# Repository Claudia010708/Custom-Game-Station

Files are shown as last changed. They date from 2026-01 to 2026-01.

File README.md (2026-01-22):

# Custom-Game-Station
Project results of "ASSIST HEIDI - Designing and implementing Assistive Tools for people with disabilities" course.

A Custom Game Station designed for specifical needs of our co-designer. It is a multifunctional adaptive system projected to replace standard joystick and triggers. Specifically, the user requested a customized system to play "Blue Prince", a game requiring strategic navigation and interaction, but can be adapted to easily play multiple games.

## Product overview
This solution is composed of 1 Puck.js microcontroller, which could be easily connected wirelessly to a PC through web Bluetooth. Connected to this, 2 switch buttons and a custom 3D printed support. The solution is meant to be applied on a wheelchair.

    

## Key Features
Wheelchair Joystick:
* Could work both as PC mouse or WASD keys on keyboard, it depends on the selected modality
* Could be recalibrated every time needed
* Adjustable Sensitivity: Settings to adjust joystick sensitivity to individual needs.

Top Cover:
* Holds the batteries for the Puck.js
* Hosts a switch button
* Hosts a plug-in connector to an additional button, the Side-Knee-Button

Side-Knee-Button:
* Is mounted on a Side-Knee-Holder, meant to be attached on the inner side of the wheelchair
* Easy to use, convenient positioning and easy operation with minimal effort

## Technical specifications
* Microcontroller: Puck.js with Bluetooth Low Energy (BLE) support
* Power Supply: Battery-powered with two AAA Alkaline (1.5 V) batteries
* Compatibility: Compatible with Windows, macOS, and Linux operating systems
* Range: Up to 10 meters wireless range.

## Material
* 1x Puck.js microcontrollers
* Glue
* 5x Pair of small connectors
* 2x Switch buttons
* 1x Jack Connector
* 3D printed devices (Joystick Top, Joystick cap, Top Cover, Side Knee holder, Side Knee Button holder)
* Elastic band 10 mm thick

## User Documentation
* [Additional information - About our Project](Additional_Information.pdf)
* [User Manual](User%20Manual/)
* [CAD files](CAD%20Files/)

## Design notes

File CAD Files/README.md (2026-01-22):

# 3D Printing Instructions

This section provides the optimal printing parameters used for the components of the **ASSIST HEIDI** project (STL files included in this repository).

## 🖨️ Print Settings (Slicer Configuration)

Based on the verified configurations from **PrusaSlicer** shown in the documentation:

| Parameter | Setting |
| :--- | :--- |
| **Printer** | Original Prusa i3 MK3S & MK3S+ |
| **Nozzle Diameter** | 0.6 mm |
| **Layer Height** | 0.30 mm (Quality) |
| **Filament** | Prusa PLA |
| **Infill** | 15% |
| **Supports** | Organic, Everywhere |
| **Brim** | Enabled (for extra bed adhesion) |

## 💰 Printing Estimates (Cost & Time)

Below are the estimated costs and printing times calculated using **PrusaSlicer** (Normal Mode):

| Component / Plate | Included Files | Estimated Cost | Printing Time |
| :--- | :--- | :---: | :---: |
| **Cover** | cover_fin14.01.3mf | € 1.64 | 2h 33m |
| **Accessories Kit** (Printed together) | side holder.stl, Side knee button 3.0.stl, Joystick cap.stl, my Joystick body.stl | € 1.74 | 3h 34m |

> **Tip:** The accessories are optimized to be printed simultaneously on the same build plate.

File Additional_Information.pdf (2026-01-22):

# Custom-Game-

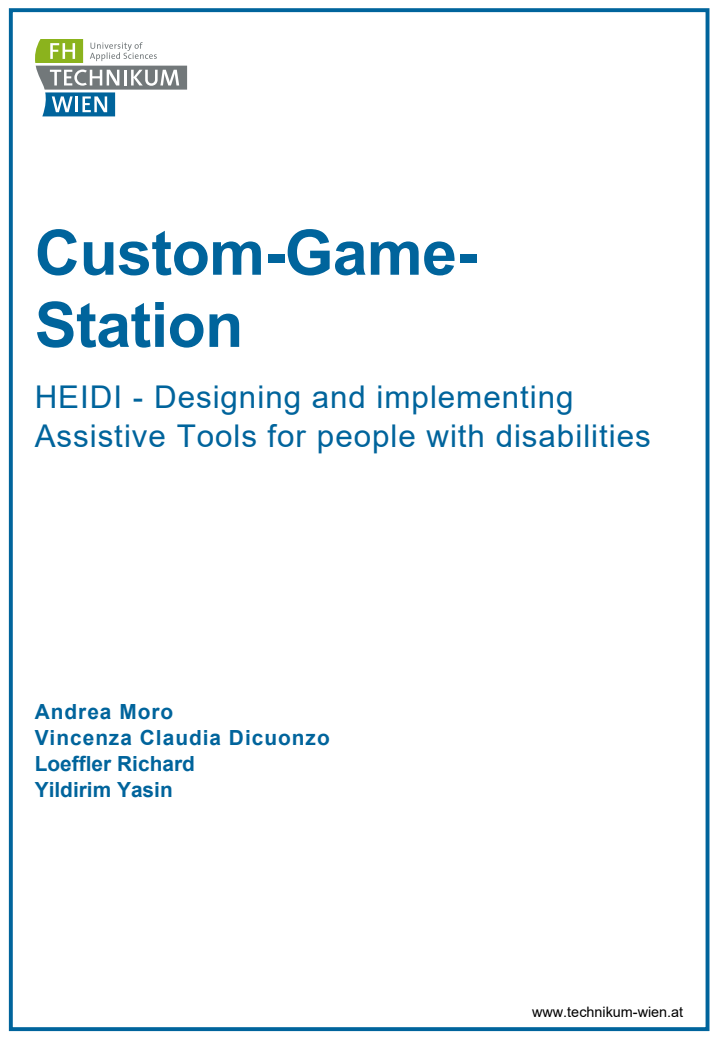
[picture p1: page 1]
Station

HEIDI - Designing and implementing
Assistive Tools for people with disabilities

Andrea Moro
Vincenza Claudia Dicuonzo
Loeffler Richard (https://moodle.technikum-wien.at/user/view.php?id=36255&course=31281)
Yildirim Yasin (https://moodle.technikum-wien.at/user/view.php?id=36939&course=31281)

www.technikum-wien.at

# PROJECT OVERVIEW

Project results of "ASSIST HEIDI - Designing and implementing Assistive Tools for people with disabilities" course.

### Our Team

The Trentino Team “For this project, we embraced the challenge to better understand the possibilities that assistive technologies offer. Our journey focused on bridging the gap between technical constraints and human-centered design.”

### Problem Statement and User Request

The primary challenge regards the fact that conventional gaming controllers require fine motor precision, which results inaccessible to the user. The goal was to design and develop a multifunctional adaptive system to replace standard joysticks and triggers. Specifically, the user requested a customized interface to play "Blue Prince", a game requiring strategic navigation and interaction that, in its original form, exceeded the physical reach and coordination capabilities of our co-designer.

The user is affected by Cerebral Palsy, characterized by poor coordination, muscle stiffness (spasticity), weakness, and tremors. These factors make traditional button-mapping or holding a controller impossible.

Despite these limitations, the following residual functions were identified as inputs for the adaptive system:

- Upper Body: Control of the left arm (though movements are stiff).
- Motor Skills: Sufficient dexterity in the left hand to operate a communication device keyboard and a wheelchair joystick.
- Lower Body: Capability to extend both legs from a sitting position and perform seated knee raises and lateral movements.
- Ocular Control: High proficiency in using eye-tracking systems.

### Solution developed

The implemented solution is a custom Assistive Game Station designed to translate physical actions into digital gameplay. It consists of:

- Smart Joystick: Equipped with a Puck.js microcontroller that senses physical tilts and translates them into in-game perspective and movements.
- Dual-Button Interface: Includes two mechanical switches to replace basic game functions, specifically designed for games that do not require high-speed or fine motor control.

Our project builds upon the foundations of the "Wheely-Joystick-Mouse", an open-source initiative, available here: https://github.com/inclusion-international/Wheely-Joystick-Mouse.git

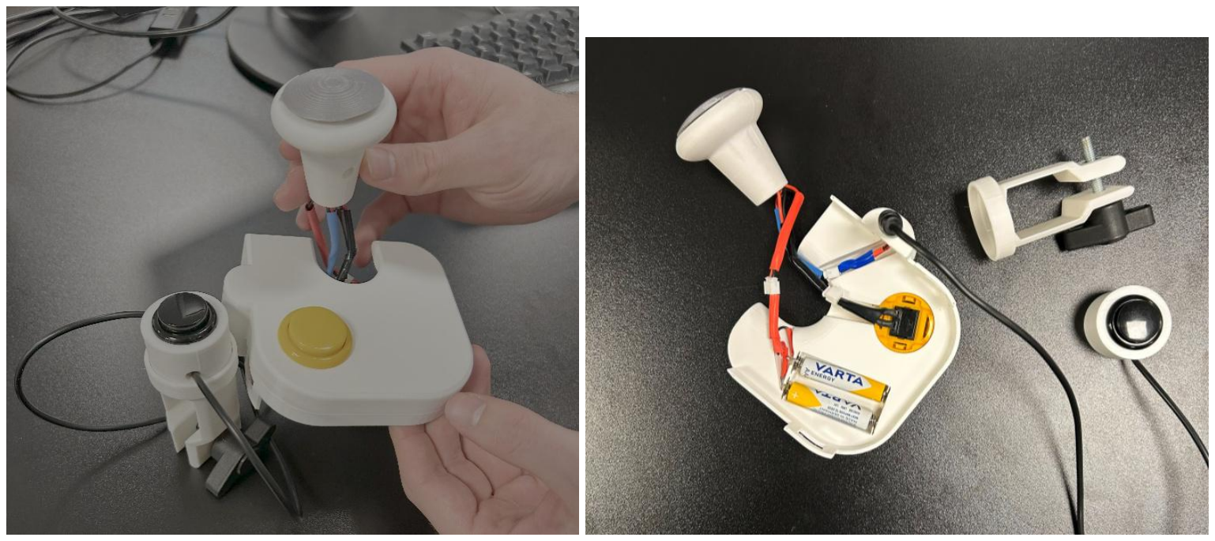
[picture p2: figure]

### Accessories and Instructions

### Cost Estimation

The final product, including the Puck.js microcontroller, mechanical buttons, 3D printed components, and connectors, is estimated to cost between €42 and €43. This makes the device a cost-effective assistive solution compared to commercial alternatives.

### System Usage

Following the instructions provided in the “User manual“, alongside a detailed “Electrical scheme“ it is possible to mount and run the final system.

Once mounted, the system operates wirelessly via Bluetooth. The user can interact with the game by tilting the joystick (sensing movements through the Puck.js) and using the two mechanical buttons for primary game functions. The side knee button is specifically positioned to allow for accessible triggering without requiring fine hand motor control. The details about the translation of the commands are also available in the ”User manual”.

### Acknowledgments

This project was developed within the framework of the ASSIST HEIDI initiative, drawing inspiration from and building upon established open-source assistive controller concepts. We would like to express our gratitude to our co-designer for their participation throughout the co-creation process; their continuous feedback and testing were fundamental in shaping the final prototype to meet realworld accessibility needs

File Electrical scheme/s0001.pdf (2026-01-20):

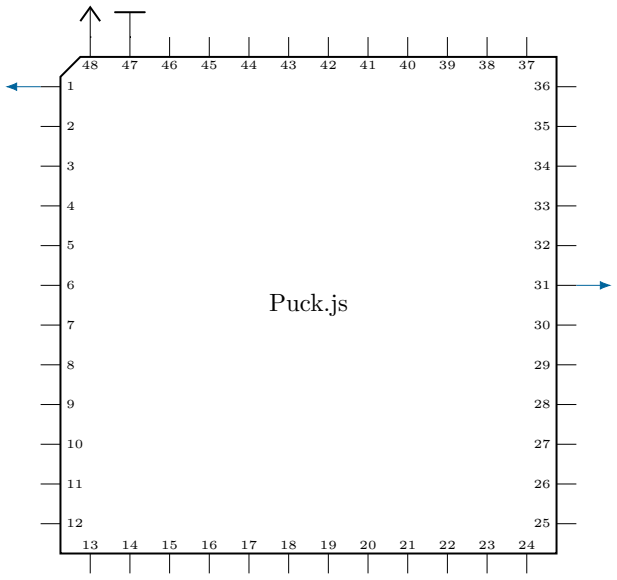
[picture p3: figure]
Puck.js
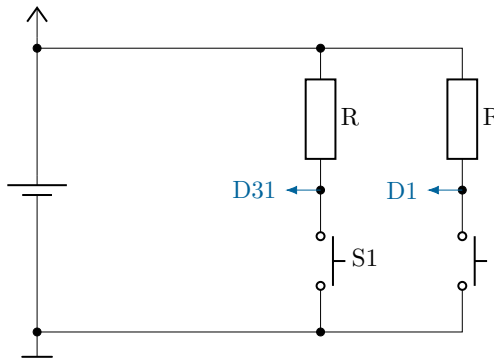
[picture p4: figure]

3V

R

S2

# VCC

# VCC

D31

D1

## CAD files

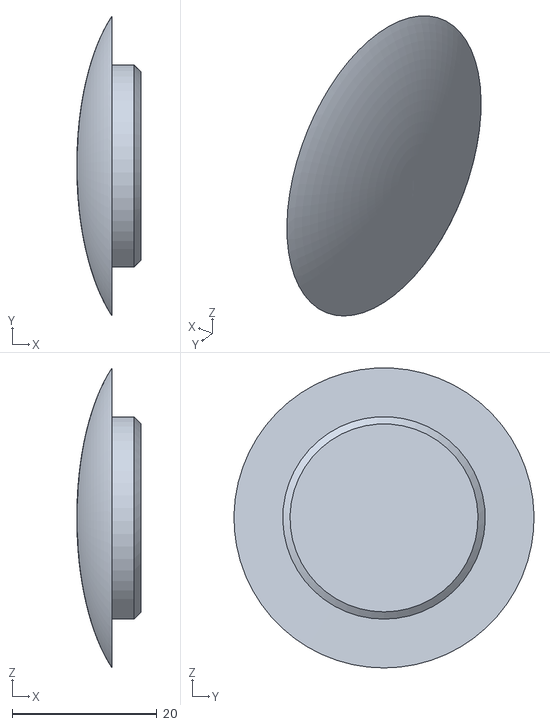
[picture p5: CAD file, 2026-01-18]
Joystick cap.stl
8.90 x 41.5 x 41.5

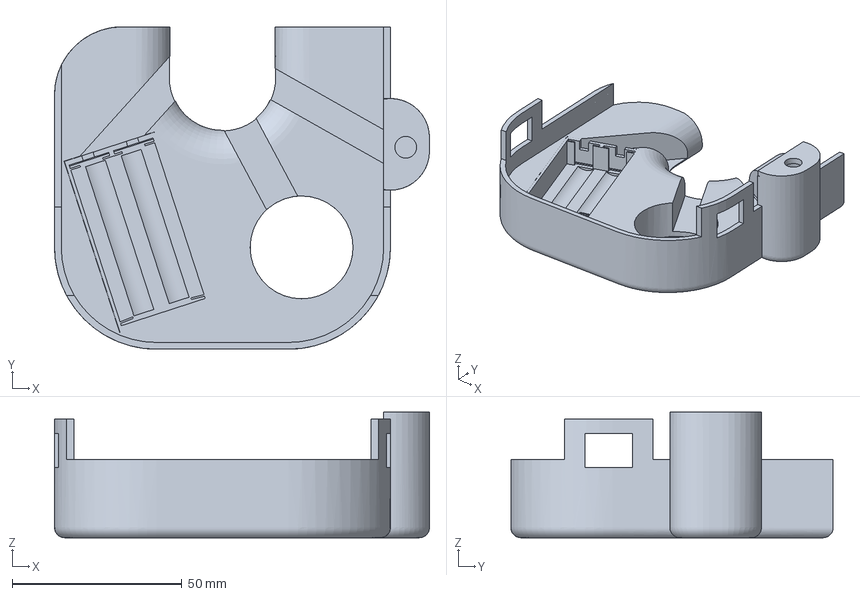
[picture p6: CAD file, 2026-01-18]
cover_fin14.01.3mf
110.5 x 95.0 x 37.0 mm

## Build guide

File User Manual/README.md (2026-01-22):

# User Manual

# Installation Instructions

* Web Connection

1. Open the [Espruino Web IDE](https://www.espruino.com/ide/) on your browser
2. Connect your Puck.js to your computer via Bluetooth (Top-left button)
3. Load the firmware [main code](Code/HEIDI_Final_Code.js) into the Espruino Web IDE.
4. Check on the "Access files in device's storage" the presence of the [Switch Button code[(Code/SWBtn_Final_Version.js). This code should be stored as "SWBtn".
5. Click the "Send to Espruino (Flash)" button in the IDE to upload the firmware to your Puck.js.
6. When the process is done, a message should appear in the console log in the right.

* Computer Connection

1. Click on the Top-Left button to disconnect temporanealy the microcontroller.
2. Now connect it via traditional Bluetooth of your own PC.
3. Now the Game-Station is ready to be used.

# 🛠️ Mounting Specifications

Follow these instructions to correctly assemble and install the Custom Game Station on the wheelchair.

### 1. Component Assembly
* **Joystick Core:** Insert the **Puck.js** microcontroller into the **Joystick Body**. Secure the assembly by snapping the **Joystick Cap** on top.
* **Side Control:** Attach the **Side Knee Button** to the **Side Holder**.

### 2. Wheelchair Preparation
* **Removal:** Carefully remove the original rubber cover from the wheelchair's joystick shaft.
* **Wiring & Connectivity:** * Follow the established color code to connect the internal joystick wires.
    * Connect the wires to the button integrated into the cover and to the plug-in connector for the lateral (knee) button.

### 3. Final Installation & Securing
* **Joystick:** Slide the new 3D-printed cover onto the joystick rod.
* **Base Cover:** Position the cover firmly onto the joystick base. To prevent movement and ensure a stable fit, attach two elastic bands to the lateral hooks:
    * One elastic band around the back side of the joystick base.
    * The second elastic band underneath the base.
* **Side Button Mounting:** Install the Side Holder onto the inner frame of the wheelchair. Adjust the screw to rotate and fix the button in the user's desired ergonomic position.
* **Final Connection:** Plug the cable from the side knee button into the main cover socket.

# Element description

The core element is a custom joystick cover, designed to fit onto a personal wheelchair-joystick, with a Puck.js chip inside. This chip works as a sensor: it detects the joystick movements and translates them into different game actions.
Furthermore there is a special cover, which contains the batteries for joystick power supply, host a so-called cover-button, and provide the link for the side-knee-button. This last button is meant to be positioned near the knee, under the cover.

* Detailed functions

Before playing a calibration step is required. By performing a long press (~ 2 seconds) on the cover button, the system automatically execute the calibration of the Puck.js’ accelerometer to ensure that joystick movements are interpreted correctly and precisely. After this step the game station is ready to be used. It is also possible to perform the calibration at anytime, by a long press of the cover button.

* Side-knee-button

A short press of this button (1 click) is translated into the left click of the mouse, so make the player interact with the game environment. A long press of this button will change the joystick behaviour: this feature let the player change between the movement control (the WASD keys) and the perspective point of view (the mouse movement), and vice versa. This allows the player to navigate and look around using the same joystick without needing extra devices.

* Top cover-button

A short press of this button (1 click) is translated into the TAB button of the keyboard. This is just a shortcut to let the player be able to open the map in the game with less effort. As already said, the long press of this button perform the calibration of the accelerometer.

* Other aspects

The 3 wires between the joystick and the cover must match their color type (Black, Blue, Red): one for battery supply, and one for each button.
Inside the cover there is the space for batteries: they are AAA battery (1.5 V each). In this way they could be replaced easily
The cover has to be fixed in place: for this reason, an elastic bandage is helpful and provide stability to the system.
